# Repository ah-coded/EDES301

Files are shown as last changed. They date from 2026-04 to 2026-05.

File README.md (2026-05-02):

<h1> EDES 301 </h1>
Repository for EDES301 course work

Project_01 Contains code to run the wificar, including the code for both the Laptop side and Pocketbeagle side.
NOTE! Ensure to input your own hotspot IP address before attempting to test. 

Project_02 Contains files to generate a ESP32 version of the project, with a custom footprint for the ESP32. 

Link to Hackster page: https://www.hackster.io/ah275/wrc-wifi-rally-car-f0a445

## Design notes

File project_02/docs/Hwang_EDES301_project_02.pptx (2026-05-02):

## EDES 301 PCB Project

Aiden Hwang
Due 05/05/2025 @ 11:59pm

## Project Proposal

A realistic looking and wifi controlled fpv car.

3D Printed RC Cars
- Missing: Not wifi controlled, use of stock wheels

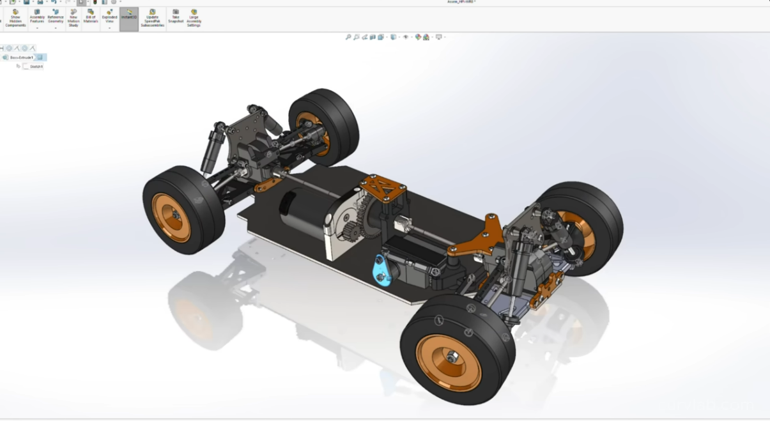
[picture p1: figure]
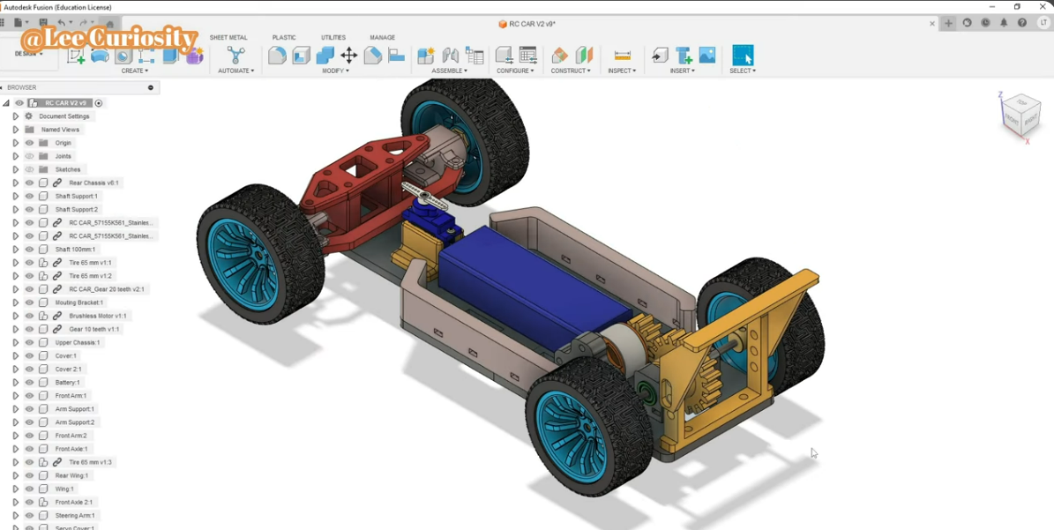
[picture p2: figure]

Wifi Controlled Car
- Missing: Slow, don’t look realistic

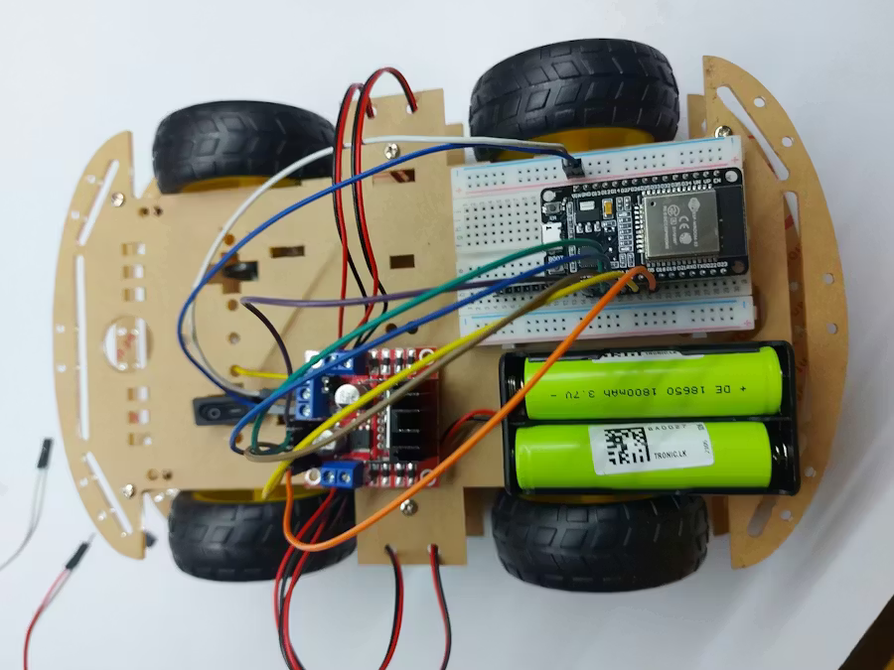
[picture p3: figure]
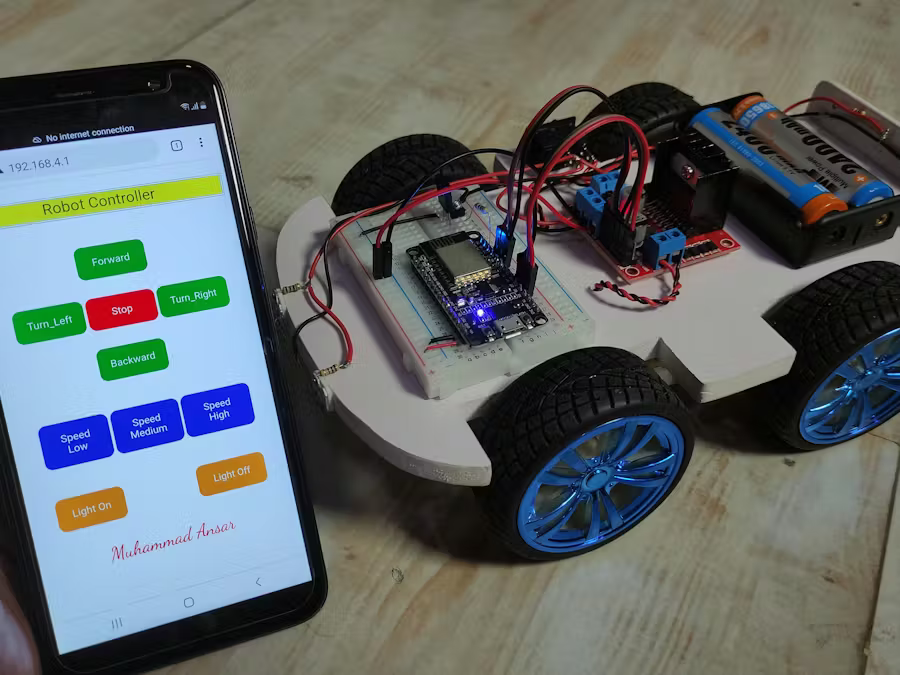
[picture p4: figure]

FPV Cars
- Missing: No cockpit view, not traditional cars

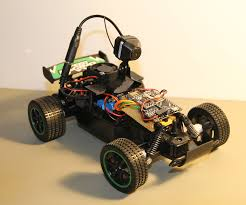
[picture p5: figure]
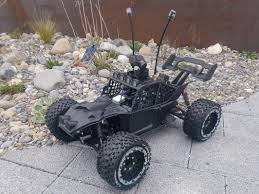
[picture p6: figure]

## SPD Block Diagram with a New Development Board (ESP32)

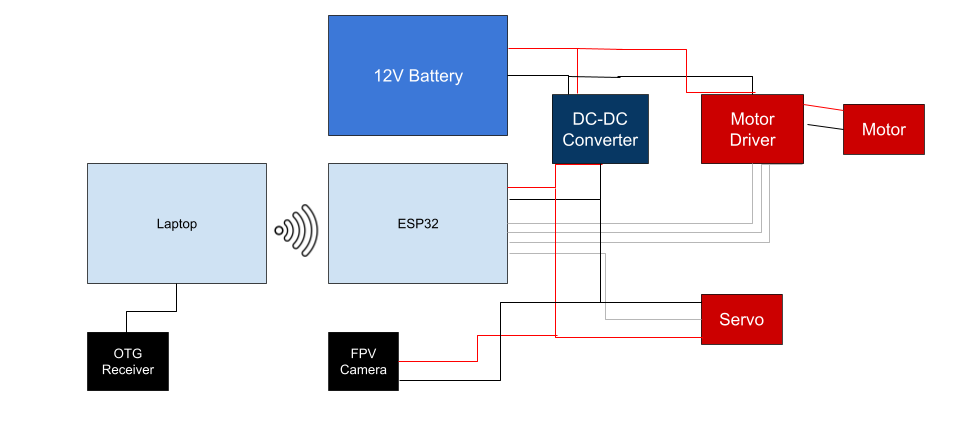
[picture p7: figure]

## Mechanical Drawing

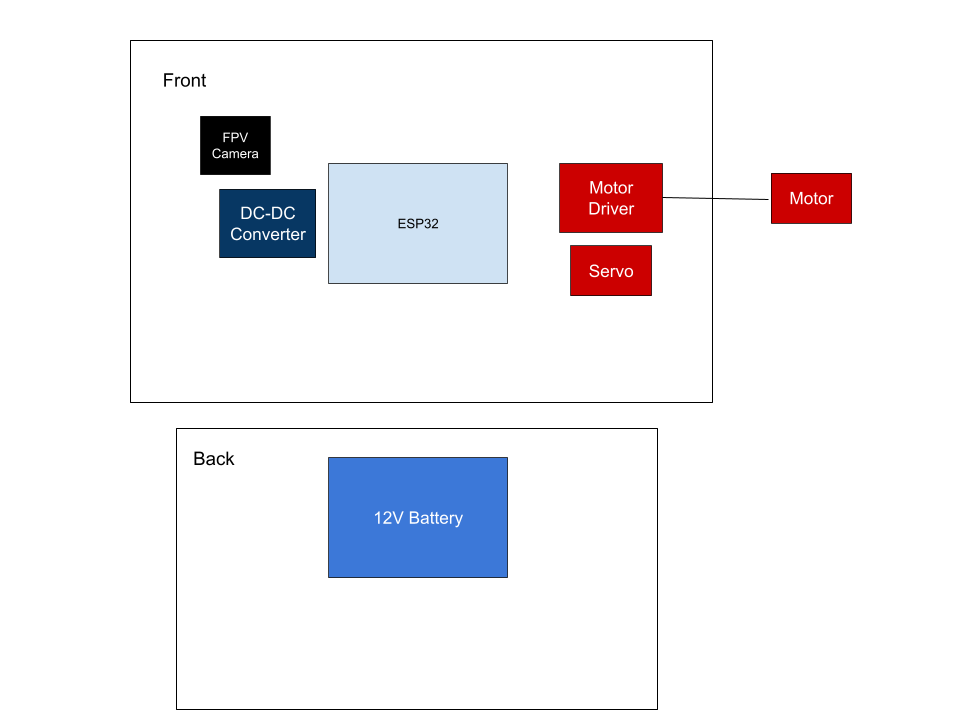
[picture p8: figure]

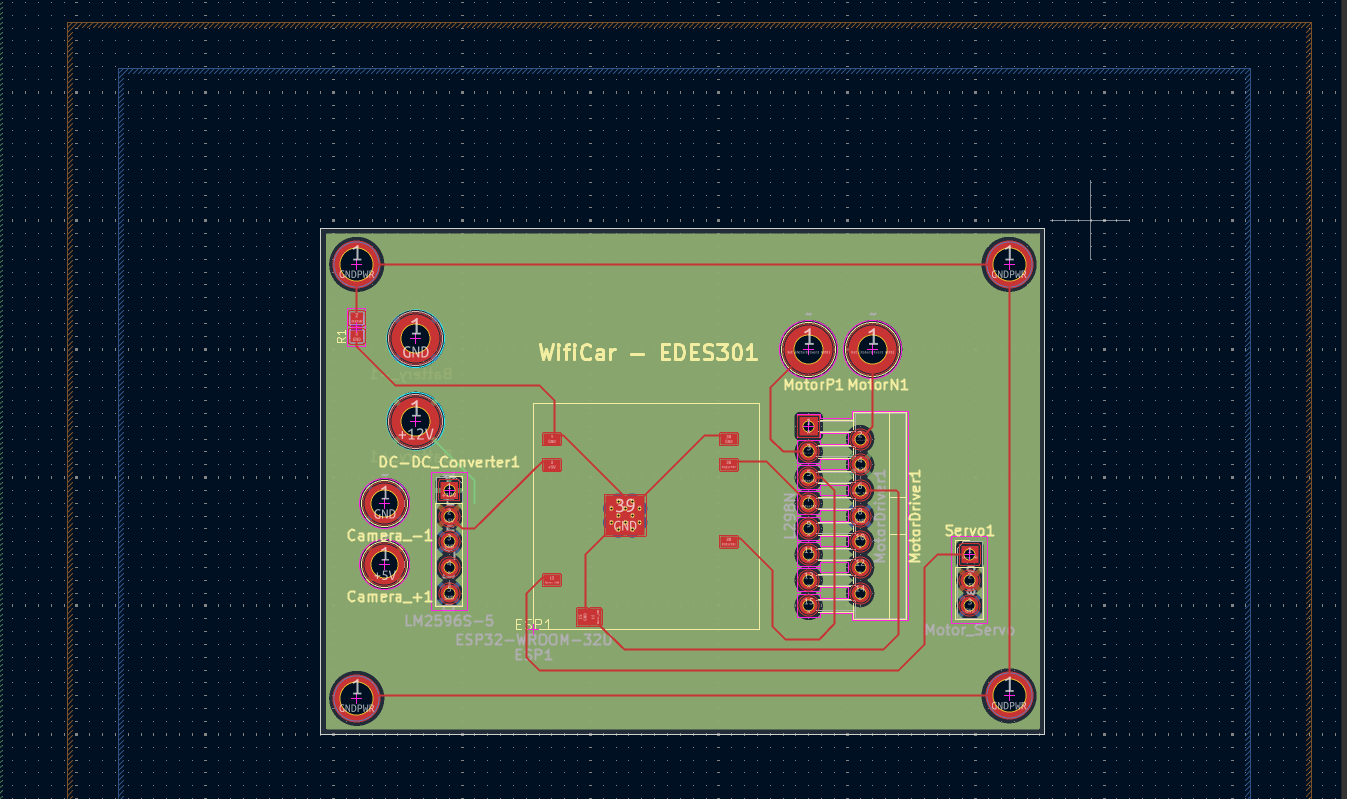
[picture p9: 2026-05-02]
project_02/docs/Screenshot 2026-05-02 083910.png

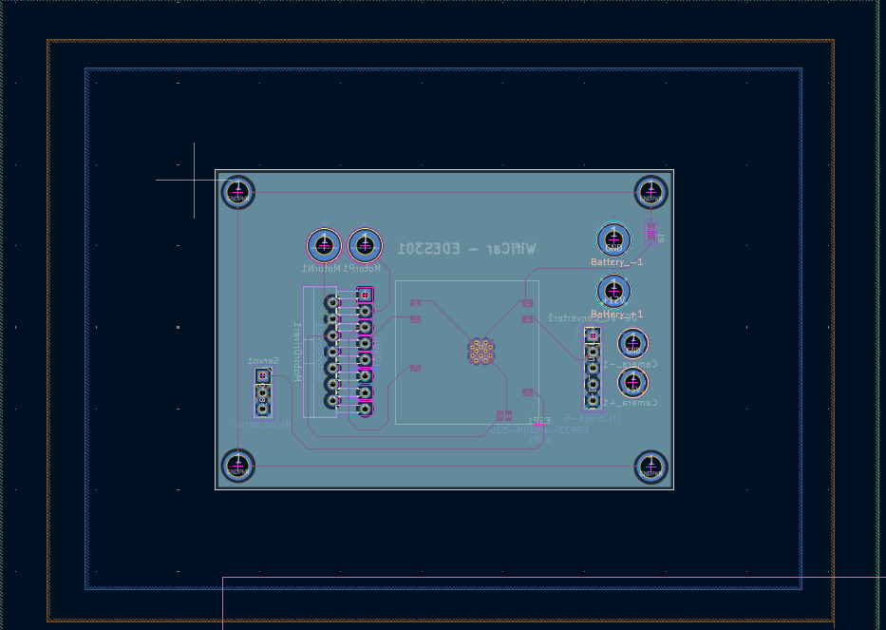
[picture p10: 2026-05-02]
project_02/docs/Screenshot 2026-05-02 083929.png

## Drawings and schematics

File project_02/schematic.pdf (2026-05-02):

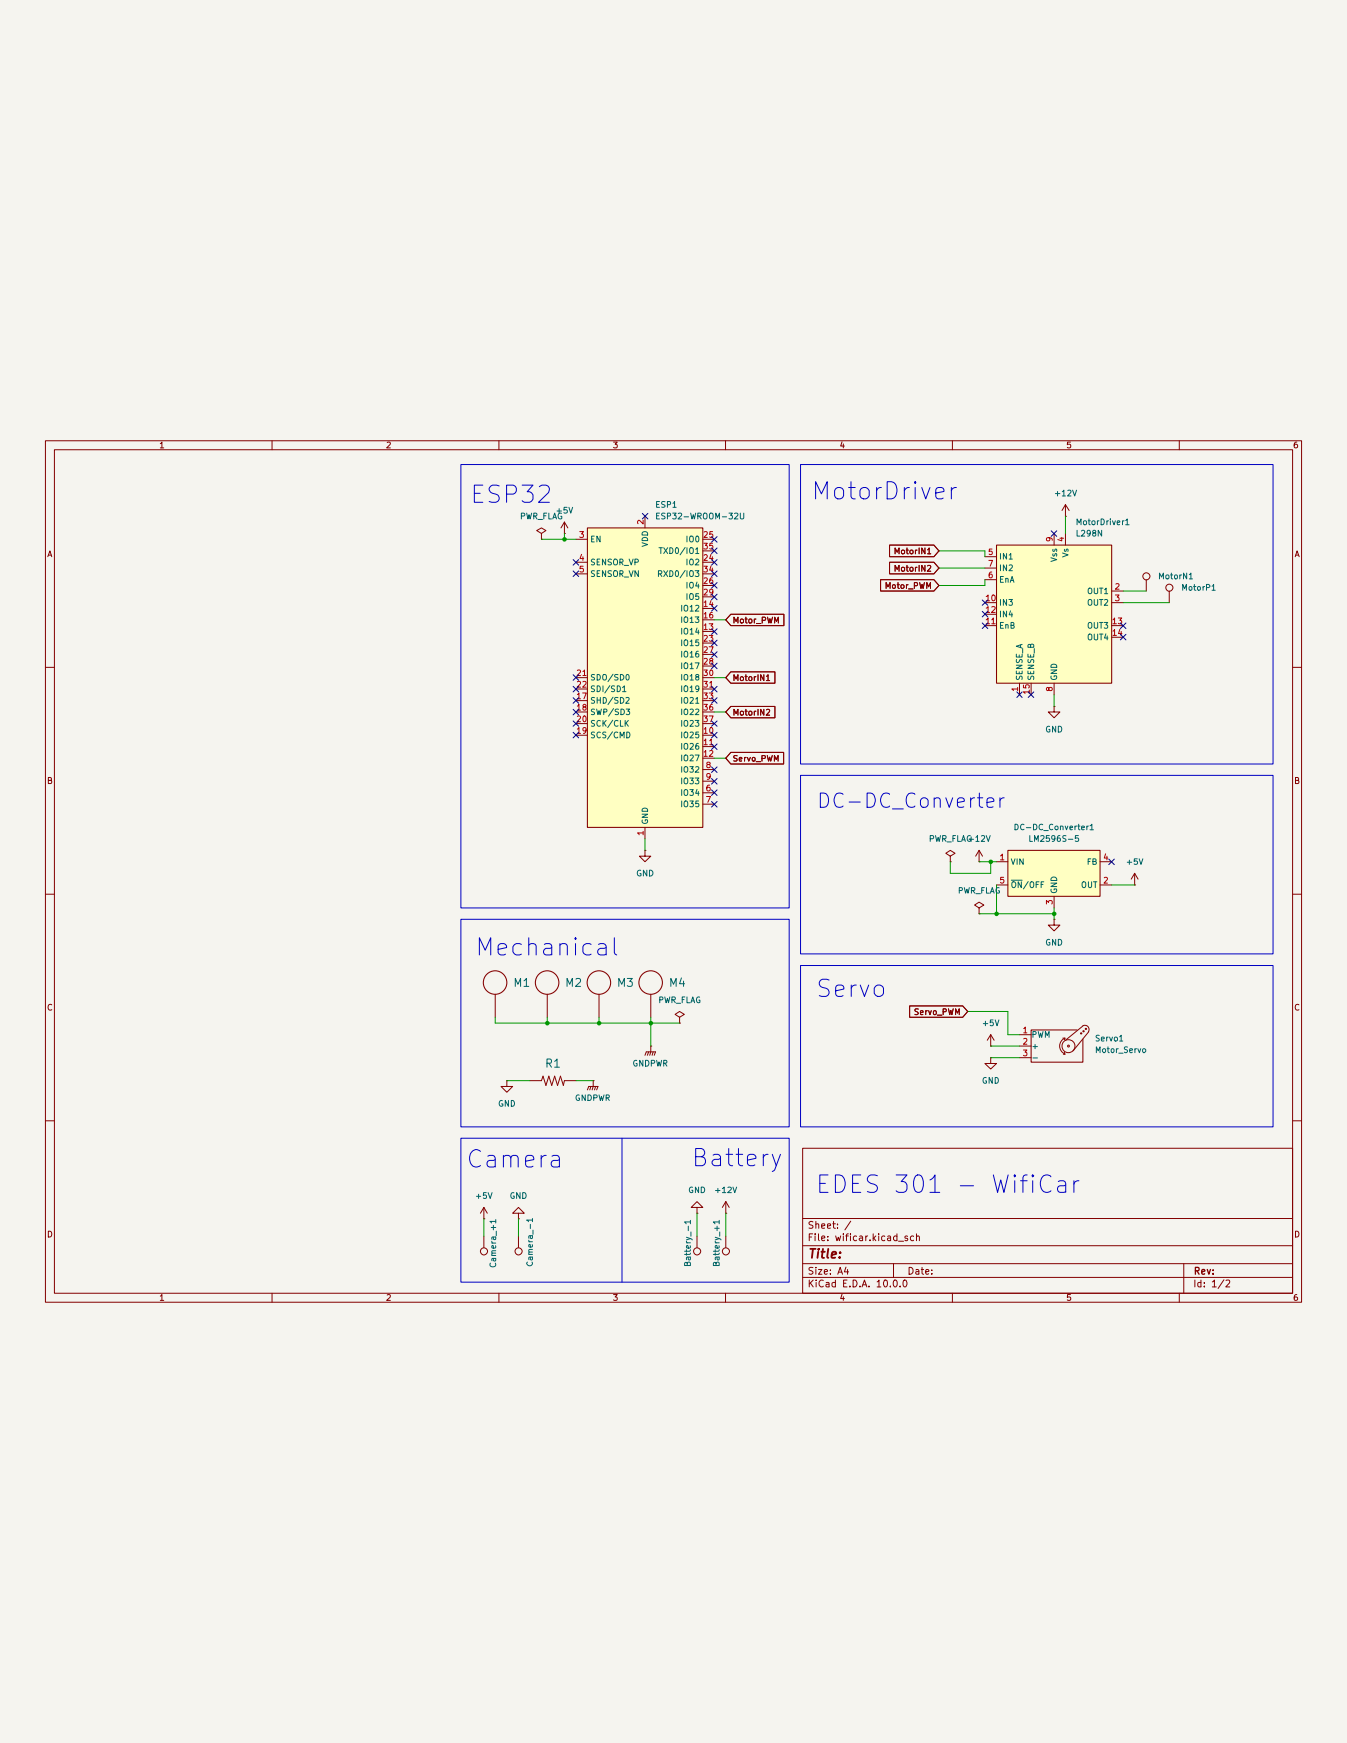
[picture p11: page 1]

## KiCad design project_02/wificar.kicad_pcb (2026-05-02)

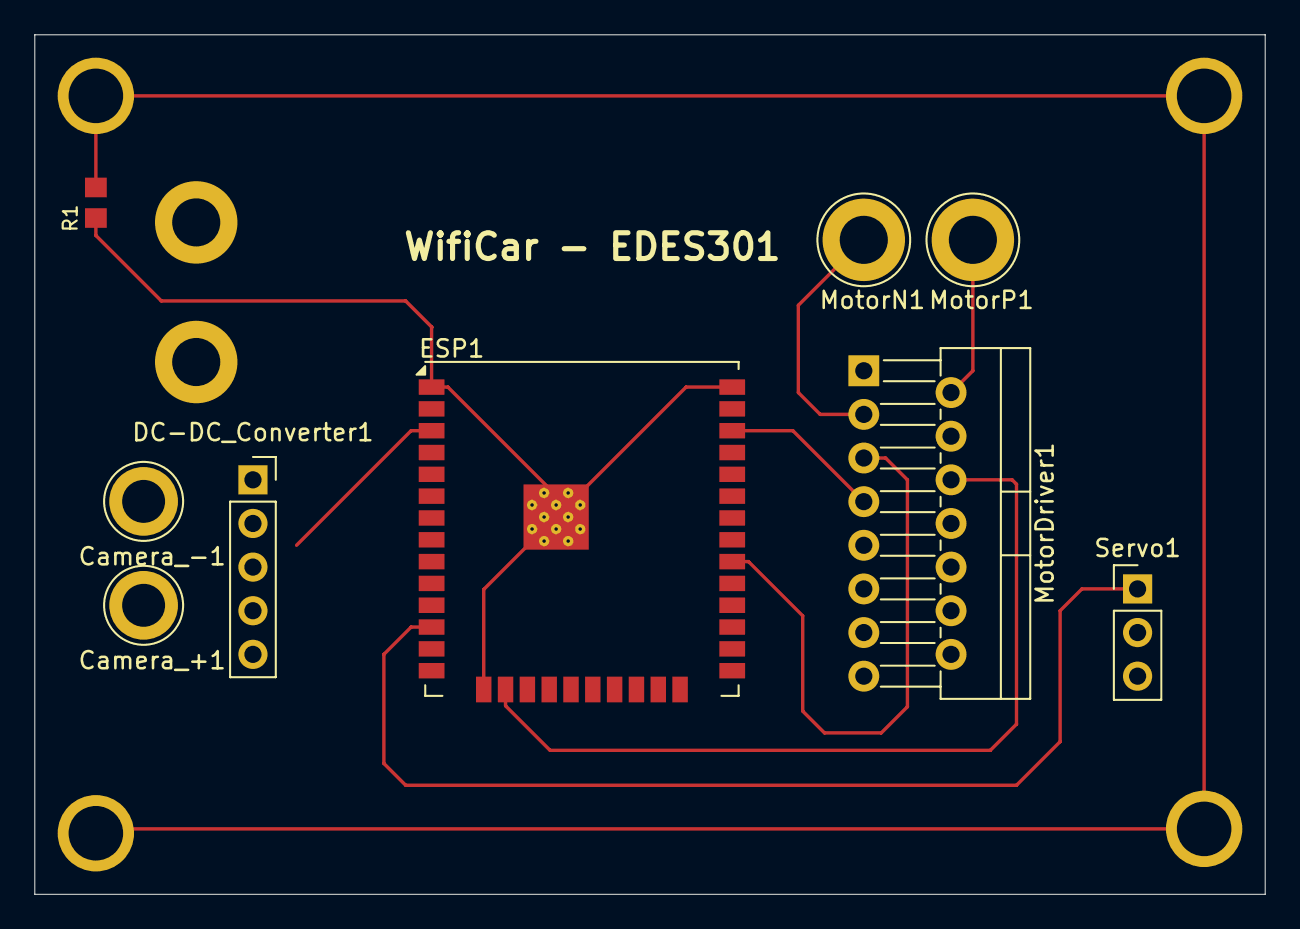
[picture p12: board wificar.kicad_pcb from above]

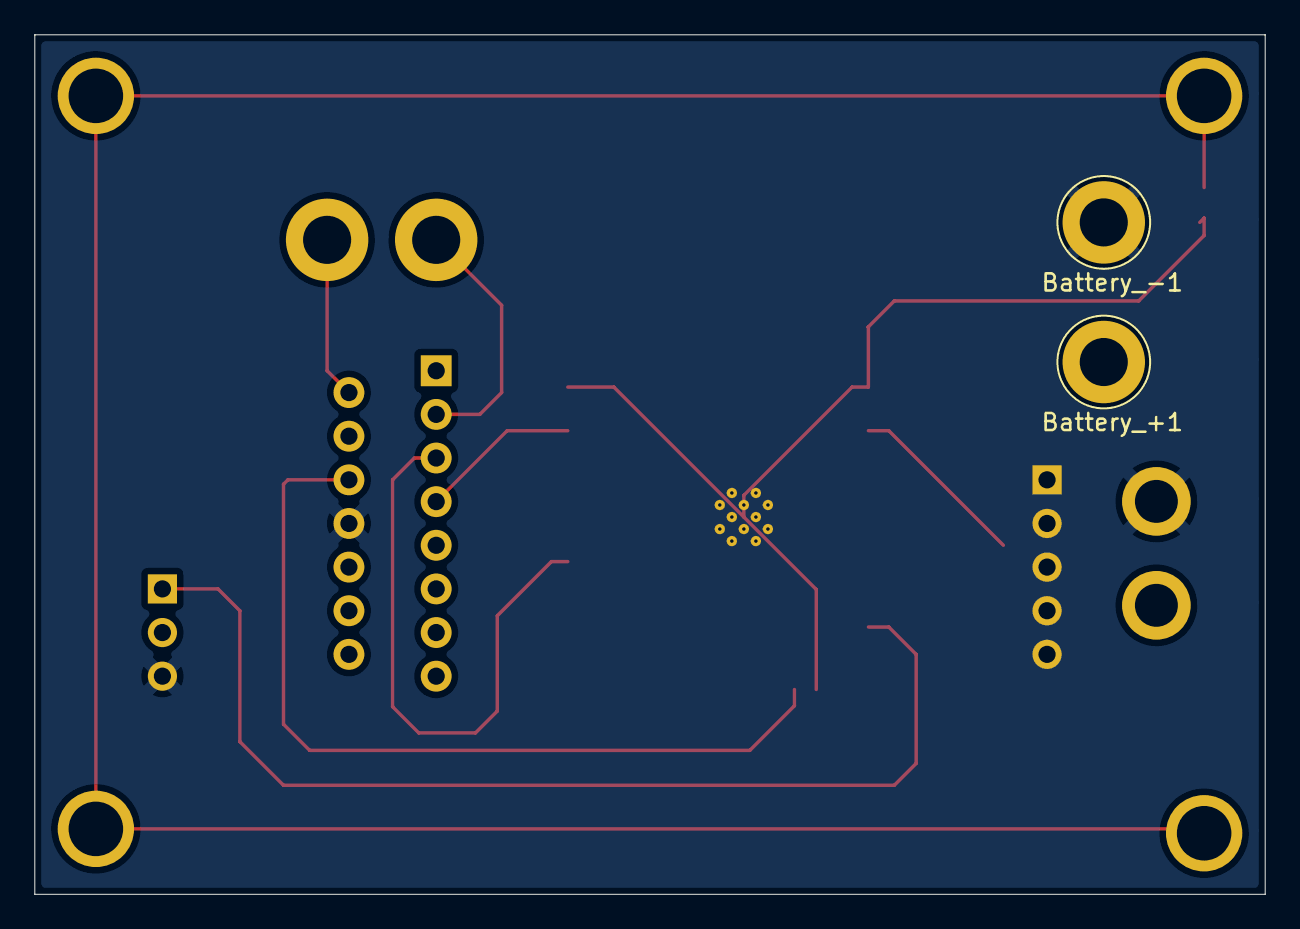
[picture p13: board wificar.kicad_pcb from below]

Board: 4 copper layers, 71.6 x 50.0 mm, 15 parts (2 on the bottom side), 10 nets.

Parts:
Battery_+1: TestPoint_Loop_D3.80mm_Drill2.8mm
Battery_-1: TestPoint_Loop_D3.80mm_Drill2.8mm
Camera_+1: TestPoint_Loop_D3.80mm_Drill2.5mm
Camera_-1: TestPoint_Loop_D3.80mm_Drill2.5mm
DC-DC_Converter1: LM2596S-5; PinSocket_1x05_P2.54mm_Vertical
ESP1: ESP32-WROOM-32U
M1, M2, M3, M4: MOUNTING_HOLE
MotorDriver1: L298N; TO-220-15_P2.54x5.08mm_StaggerOdd_Lead4.58mm_Vertical
MotorN1: TestPoint_Loop_D3.80mm_Drill2.8mm
MotorP1: TestPoint_Loop_D3.80mm_Drill2.8mm
R1: R0805
Servo1: Motor_Servo; PinHeader_1x03_P2.54mm_Vertical

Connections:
+5V: Camera_+1.1 (1_1), DC-DC_Converter1.2 (OUT), ESP1.3 (EN), Servo1.2 (+)
+12V: Battery_+1.1 (1_1), DC-DC_Converter1.1 (VIN), MotorDriver1.4 (Vs)
GND: Battery_-1.1 (1_1), Camera_-1.1 (1_1), DC-DC_Converter1.3 (GND), DC-DC_Converter1.5 (~ON/OFF), ESP1.1 (GND), ESP1.15 (GND), ESP1.38 (GND), ESP1.39 (GND), MotorDriver1.8 (GND), R1.1, Servo1.3 (-)
GNDPWR: M1.1 (1_1), M2.1 (1_1), M3.1 (1_1), M4.1 (1_1), R1.2
MotorIN1: ESP1.30 (IO18), MotorDriver1.5 (IN1)
MotorIN2: ESP1.36 (IO22), MotorDriver1.7 (IN2)
Motor_PWM: ESP1.16 (IO13), MotorDriver1.6 (EnA)
unnamed: MotorDriver1.2 (OUT1), MotorN1.1 (1_1)
unnamed: MotorDriver1.3 (OUT2), MotorP1.1 (1_1)
Servo_PWM: ESP1.12 (IO27), Servo1.1 (PWM)

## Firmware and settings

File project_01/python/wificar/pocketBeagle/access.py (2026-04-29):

#!/bin/bash
# --------------------------------------------------------------------------
# Wificar - Wifi Access Script
# --------------------------------------------------------------------------
# License:   
# Copyright 2026 Aiden Hwang
# 
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
# 3. Neither the name of the copyright holder nor the names of its contributors 
# may be used to endorse or promote products derived from this software without 
# specific prior written permission.
# 
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
import socket
import Adafruit_BBIO.PWM as PWM
import Adafruit_BBIO.GPIO as GPIO

class DCMotor:
    def __init__(self, pwm_pin, in1_pin, in2_pin):
        self.pwm_pin = pwm_pin
        self.in1 = in1_pin
        self.in2 = in2_pin
        
        # Setup Pins
        GPIO.setup(self.in1, GPIO.OUT)
        GPIO.setup(self.in2, GPIO.OUT)
        PWM.start(self.pwm_pin, 0, 1000)

    def drive(self, direction_byte, speed_byte):
        speed_pct = speed_byte / 2.55  # Convert 0-255 to 0-100
        
        if direction_byte == 170:    # Forward
            GPIO.output(self.in1, GPIO.HIGH)
            GPIO.output(self.in2, GPIO.LOW)
            PWM.set_duty_cycle(self.pwm_pin, speed_pct)
        elif direction_byte == 187:  # Reverse
            GPIO.output(self.in1, GPIO.LOW)
            GPIO.output(self.in2, GPIO.HIGH)
            PWM.set_duty_cycle(self.pwm_pin, speed_pct)
        else:                        # Stop
            GPIO.output(self.in1, GPIO.LOW)
            GPIO.output(self.in2, GPIO.LOW)
            PWM.set_duty_cycle(self.pwm_pin, 0)

    def stop(self):
        PWM.stop(self.pwm_pin)


class SteeringServo:
    def __init__(self, pwm_pin, min_dc=5, max_dc=10):
        self.pwm_pin = pwm_pin
        self.min_dc = min_dc
        self.max_dc = max_dc
        # Start at center (7.5%)
        PWM.start(self.pwm_pin, 7.5, 50)

    def set_angle(self, data_byte):
        # Formula: Min + (Range * percentage)
        servo_pos_pct = data_byte / 255
        duty_cycle = self.min_dc + (self.max_dc - self.min_dc) * servo_pos_pct
        PWM.set_duty_cycle(self.pwm_pin, duty_cycle)

    def stop(self):
        PWM.stop(self.pwm_pin)

# --- Configuration & Initialization ---

UDP_IP_ADDRESS = #hotspot IP address
UDP_PORT_NO = 3553

# Instantiate our objects
motor = DCMotor(pwm_pin="P2_1", in1_pin="P2_4", in2_pin="P2_6")
steering = SteeringServo(pwm_pin="P1_36")

# Setup UDP
serverSock = socket.socket(socket.AF_INET, socket.SOCK_DGRAM)
serverSock.bind((UDP_IP_ADDRESS, UDP_PORT_NO))

print(f"Server online at {UDP_IP_ADDRESS}. Ready to drive.")

# --- Main Loop ---

try:
    data = None
    while True:
        # FLUSH BUFFER: Keep only latest packet
        serverSock.setblocking(False)
        try:
            while True:
                new_data, addr = serverSock.recvfrom(1024)
                data = new_data
        except BlockingIOError:
            serverSock.setblocking(True)

        if data is not None:
            # Execute commands via class methods
            motor.drive(data[0], data[2])
            steering.set_angle(data[1])

except KeyboardInterrupt:
    print("\nShutting down...")
finally:
    motor.stop()
    steering.stop()
    PWM.cleanup()
    GPIO.cleanup()
